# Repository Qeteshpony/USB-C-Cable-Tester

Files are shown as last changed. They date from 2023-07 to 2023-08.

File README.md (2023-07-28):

# USB-C Cable Tester



3D Render

[Hardware Documentation](https://qeteshpony.github.io/USB-C-Cable-Tester)

Small passive device for determining the capabilities of a USB-C Cable

This helps when you have a USB-C cable and don't know which USB-Version and other features it supports. 

The tester can of course not check for any active circuitry in the cable and might not work at all with active cables but in most cases it should give you a good overview.

| LED | Meaning |
|:---|:---|
| VBUS 1-4  | One LED for each VBUS connection in the cable. Can give a hint on power capabilities |
| VGND 1-4  | One LED for each Ground connection |
| Shield | Shows if the shielding is connected on both ends |
| USB 2.0 | Lights up when the USB2 differential pair is connected |
| USB 3.x | One LED for each set of TX/RX pairs in the cable. If only one is lit, USB3.2 will not work |
| CC | One of these must be connected, the other should not be. A dim LED *can* be a hint for an active cable |
| SBU | SideBand Use (See [USB Type-C Spec R2.0, chapter 4.3](https://www.usb.org/sites/default/files/USB%20Type-C%20Spec%20R2.0%20-%20August%202019.pdf)) - Used for alternate modes like audio and video connections |

The PCB is designed with production by JLCPCB in mind and all parts but the USB-Connectors are from their basic parts library. I strongly suggest getting these assembled since soldering the USB connectors by hand is not easy.

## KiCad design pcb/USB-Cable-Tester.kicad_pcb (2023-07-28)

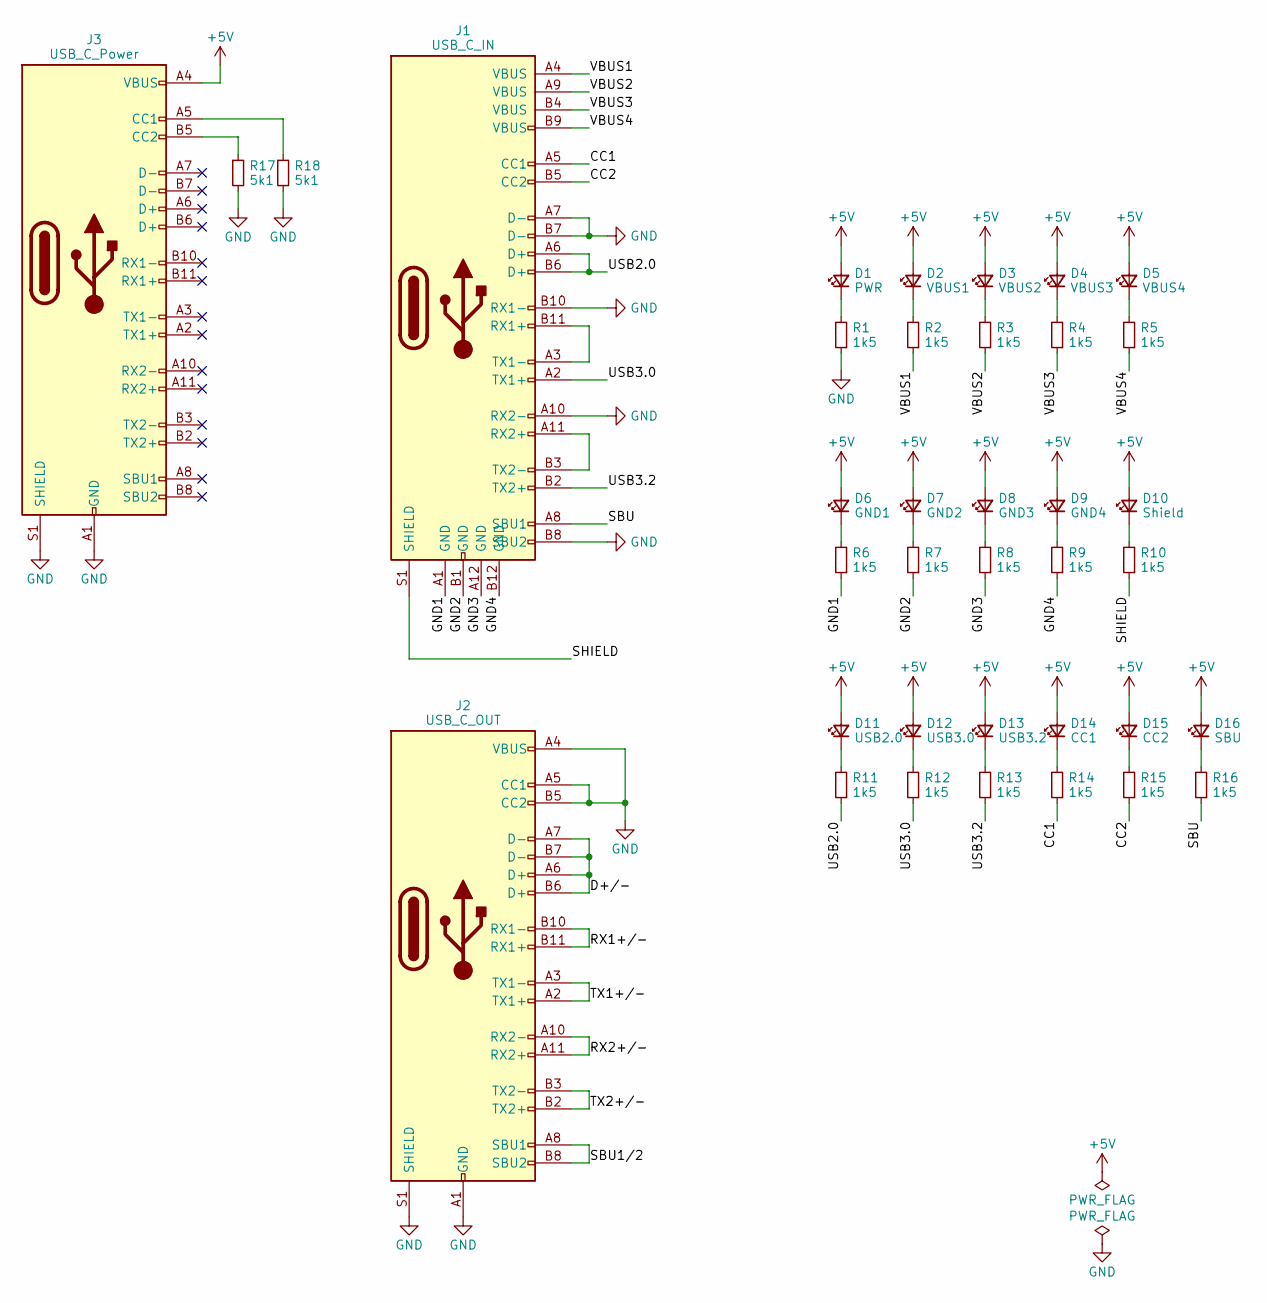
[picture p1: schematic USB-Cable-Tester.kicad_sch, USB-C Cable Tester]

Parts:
D1: PWR; LED_0603_1608Metric; LCSC C2286
D2: VBUS1; LED_0603_1608Metric; LCSC C2286
D3: VBUS2; LED_0603_1608Metric; LCSC C2286
D4: VBUS3; LED_0603_1608Metric; LCSC C2286
D5: VBUS4; LED_0603_1608Metric; LCSC C2286
D6: GND1; LED_0603_1608Metric; LCSC C2286
D7: GND2; LED_0603_1608Metric; LCSC C2286
D8: GND3; LED_0603_1608Metric; LCSC C2286
D9: GND4; LED_0603_1608Metric; LCSC C2286
D10: Shield; LED_0603_1608Metric; LCSC C2286
D11: USB2.0; LED_0603_1608Metric; LCSC C2286
D12: USB3.0; LED_0603_1608Metric; LCSC C2286
D13: USB3.2; LED_0603_1608Metric; LCSC C2286
D14: CC1; LED_0603_1608Metric; LCSC C2286
D15: CC2; LED_0603_1608Metric; LCSC C2286
D16: SBU; LED_0603_1608Metric; LCSC C2286
J1: USB_C_IN; USB_C_Receptacle_GT-USB-7028C; LCSC C3001280
J2: USB_C_OUT; USB_C_Receptacle_GT-USB-7028C; LCSC C3001280
J3: USB_C_Power; USB_C_Receptacle_GT-USB-7028C; LCSC C3001280
R1, R2, R3, R4, R5, R6, R7, R8, R9, R10, R11, R12, R13, R14, R15, R16: 1k5; R_0603_1608Metric; LCSC C22843
R17, R18: 5k1; R_0603_1608Metric; LCSC C23186

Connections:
+5V: D1.2 (A), D2.2 (A), D3.2 (A), D4.2 (A), D5.2 (A), D6.2 (A), D7.2 (A), D8.2 (A), D9.2 (A), D10.2 (A), D11.2 (A), D12.2 (A), D13.2 (A), D14.2 (A), D15.2 (A), D16.2 (A), J3.A4 (VBUS), J3.A9 (VBUS), J3.B4 (VBUS), J3.B9 (VBUS)
/CC1: J1.A5 (CC1), R14.1
/CC2: J1.B5 (CC2), R15.1
/D+/-: J2.A6 (D+), J2.A7 (D-), J2.B6 (D+), J2.B7 (D-)
/GND1: J1.A1 (GND), R6.1
/GND2: J1.B1 (GND), R7.1
/GND3: J1.A12 (GND), R8.1
/GND4: J1.B12 (GND), R9.1
/RX1+/-: J2.B10 (RX1-), J2.B11 (RX1+)
/RX2+/-: J2.A10 (RX2-), J2.A11 (RX2+)
/SBU: J1.A8 (SBU1), R16.1
/SBU1/2: J2.A8 (SBU1), J2.B8 (SBU2)
/SHIELD: J1.S1 (SHIELD), R10.1
/TX1+/-: J2.A2 (TX1+), J2.A3 (TX1-)
/TX2+/-: J2.B2 (TX2+), J2.B3 (TX2-)
/USB2.0: J1.A6 (D+), J1.B6 (D+), R11.1
/USB3.0: J1.A2 (TX1+), R12.1
/USB3.2: J1.B2 (TX2+), R13.1
/VBUS1: J1.A4 (VBUS), R2.1
/VBUS2: J1.A9 (VBUS), R3.1
/VBUS3: J1.B4 (VBUS), R4.1
/VBUS4: J1.B9 (VBUS), R5.1
GND: J1.A7 (D-), J1.A10 (RX2-), J1.B7 (D-), J1.B8 (SBU2), J1.B10 (RX1-), J2.A1 (GND), J2.A4 (VBUS), J2.A5 (CC1), J2.A9 (VBUS), J2.A12 (GND), J2.B1 (GND), J2.B4 (VBUS), J2.B5 (CC2), J2.B9 (VBUS), J2.B12 (GND), J2.S1 (SHIELD), J3.A1 (GND), J3.A12 (GND), J3.B1 (GND), J3.B12 (GND), J3.S1 (SHIELD), R1.1, R17.2, R18.2
unnamed: D1.1 (K), R1.2
unnamed: D2.1 (K), R2.2
unnamed: D3.1 (K), R3.2
unnamed: D4.1 (K), R4.2
unnamed: D5.1 (K), R5.2
unnamed: D6.1 (K), R6.2
unnamed: D7.1 (K), R7.2
unnamed: D8.1 (K), R8.2
unnamed: D9.1 (K), R9.2
unnamed: D10.1 (K), R10.2
unnamed: D11.1 (K), R11.2
unnamed: D12.1 (K), R12.2
unnamed: D13.1 (K), R13.2
unnamed: D14.1 (K), R14.2
unnamed: D15.1 (K), R15.2
unnamed: D16.1 (K), R16.2
unnamed: J1.A3 (TX1-), J1.B11 (RX1+)
unnamed: J1.A11 (RX2+), J1.B3 (TX2-)
unnamed: J3.A5 (CC1), R18.1
unnamed: J3.B5 (CC2), R17.1

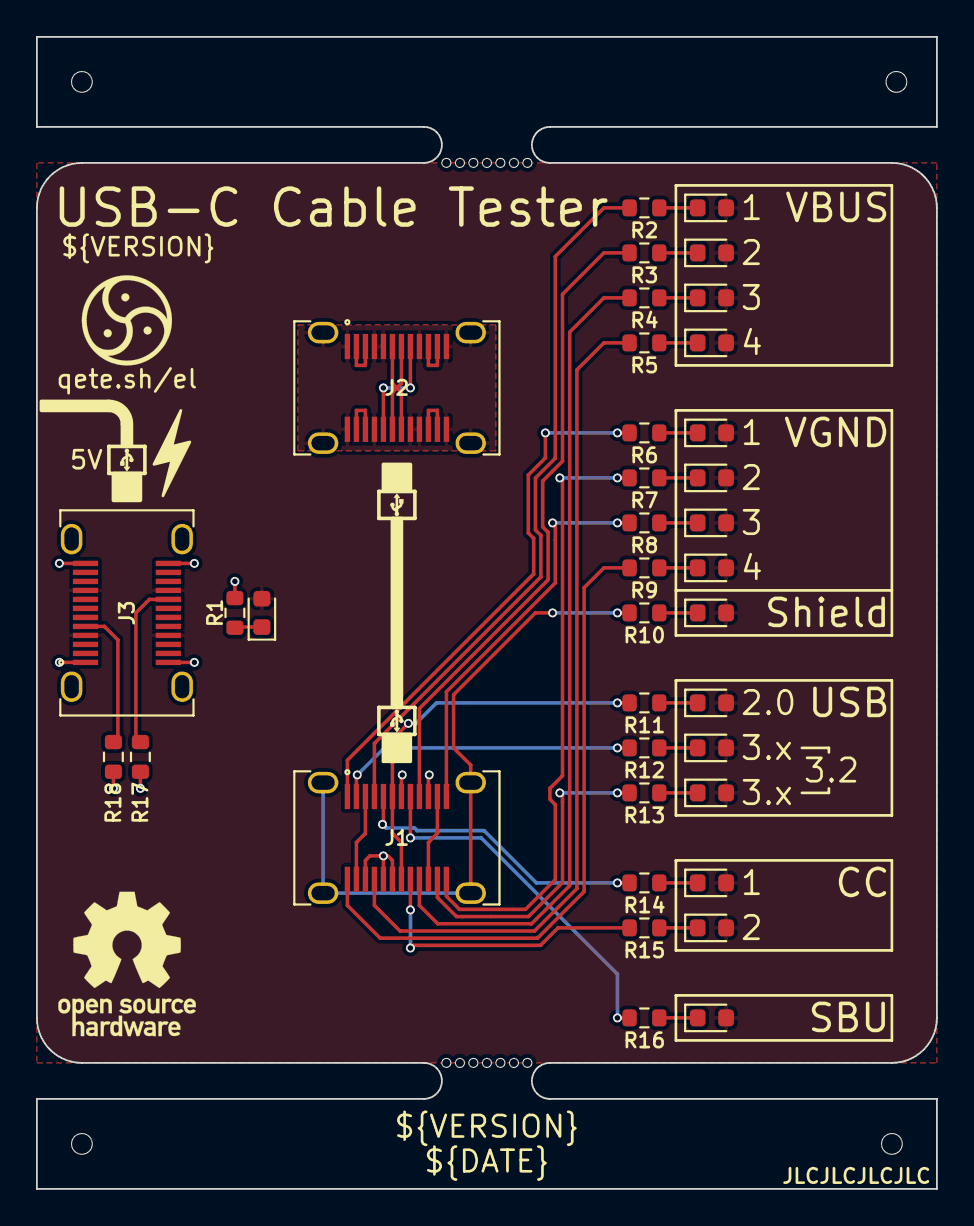
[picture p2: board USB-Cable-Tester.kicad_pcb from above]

Board: 2 copper layers, 50.0 x 64.0 mm, 39 parts (0 on the bottom side), 43 nets.

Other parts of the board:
mouse-bite-2mm-slot, mouse-bite-2mm-slot#2: VAL**; mouse-bite-2x5mm-slot-onesided-v2

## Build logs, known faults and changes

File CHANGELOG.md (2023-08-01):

# Changelog

## 1.0.0 (2023-07-28)

### Features

* initial release ([4edc850](https://github.com/Qeteshpony/USB-C-Cable-Tester/commit/4edc850d597bfacee58a50ac7f09abc1902f9b57))

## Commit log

2023-07-28 feat: initial release
    [USB-Cable-Tester.kicad_pcb, USB-Cable-Tester.kicad_sch]
2023-07-28 docs: update LED description
2023-07-28 style: silkscreen additions
    [USB-Cable-Tester.kicad_pcb]
